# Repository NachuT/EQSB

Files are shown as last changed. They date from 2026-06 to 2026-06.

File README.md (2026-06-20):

# EQSB
As a proud Iphone 7+ owner I don't enjoy many of the new updates that Apple pushes to IOS but a feature I really wish was availible to me is the built in equalizer that is now availible on IOS 27.

Screenshot 2026-06-18 at 9 42 23 PM

This prompted me to think about _physical_ equalizers where you can move physical sliders to create the changes to the music feel which led me to create this USB equalizer.

## How it works
- First, when the USB-C port is conencted to a device a USB Audio IC by TI identifies it as a audio device for us. It also splits the audio from D+ D- into Left and Right.
- Simultaneous to this a charge pump outputs a -5v value from a 5v USB input
- These voltages are used in a series of different buffers, gyrators(a op-amp configuration to simulate a inductor) and summing amplifiers
- The gyrators also have slide potentiometers attached to them allowing for an adujustable frequency to change the amounts of different frequencies of sound
- Then the adjusted left and right audio is fed into a headphone jack for listening 

## Schematic:
Screenshot 2026-06-18 at 9 52 12 PM

## PCB:
Screenshot 2026-06-18 at 9 53 24 PM

## 3d model:
Screenshot 2026-06-18 at 9 55 54 PM

## With Cad:
Screenshot 2026-06-20 at 2 28 49 PM

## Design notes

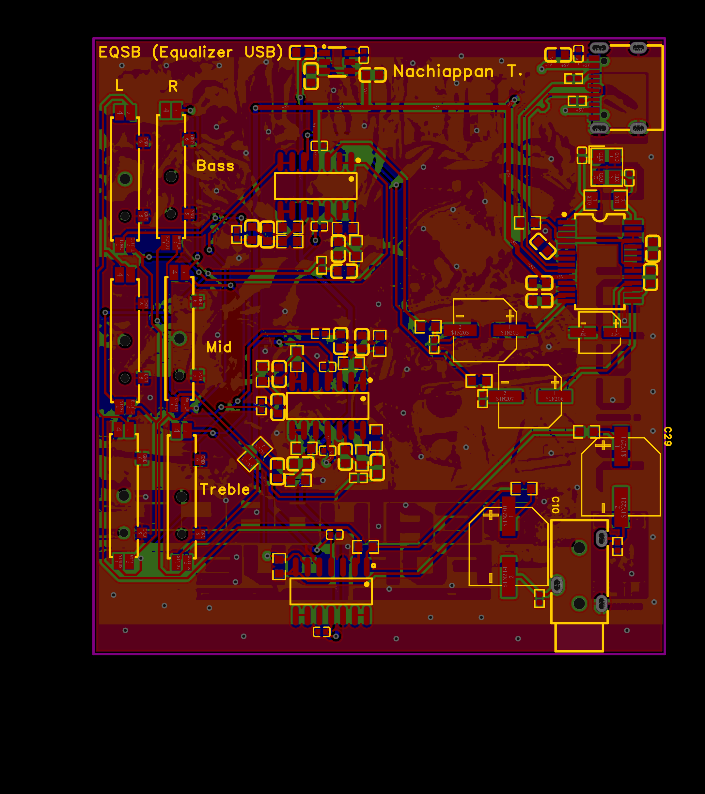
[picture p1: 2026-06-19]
PCB/PCB_PCB1_2026-06-18.png

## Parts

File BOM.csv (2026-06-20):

Name | Price | Shipping+custom+tax | Total | Note
PCB | 95.72 | 77.29 | 173.01 | No idea why shipping is this much it isnt letting me choose global standard direct line

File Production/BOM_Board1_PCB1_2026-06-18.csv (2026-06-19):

Item # | Quantity per board | Comment | Reference designators | Footprint | Value | Manufacturer Part | Manufacturer | Supplier Part | Supplier | Unique ID | Pin Count | Category | LCSC Stock | LCSC Price | JLCPCB Stock | JLCPCB Price | Layer | Mounting Style | Add into BOM | Convert to PCB | 3D Model Title | Device | Name | 3D Model Transform | JLCPCB Part Class | Description | sourceId | spicePre
1 | 7 | 100nF | C1,C30,C31,C32,C33,C34,C35 | C0402 | 100nF | CL05B104KB54PNC | SAMSUNG(三星) | C307331 | LCSC | UNIQUEC1,UNIQUEC1_0,UNIQUEC1_1,UNIQUEC1_2,UNIQUEC1_3,UNIQUEC1_4,UNIQUEC1_5 | 2 | Capacitors:Multilayer Ceramic Capacitors MLCC - SMD/SMT |  |  | 8247341 | 0.0012 | T | SMT | yes |  | C0402_L1.0-W0.5-H0.5 | CL05B104KB54PNC | 100nF | 39.37,19.685,0,0,0,0,0,0,0 | Basic Part | Capacitance:100nF Tolerance:±10% Tolerance:±10% Voltage Rating:50V Temperature Coefficient:X7R
2 | 2 | 10uF | C2,C36 | C0603 | 10uF | CL10A106MA8NRNC | SAMSUNG(三星) | C96446 | LCSC | UNIQUEC2,UNIQUEC2_0 | 2 | Capacitors:Multilayer Ceramic Capacitors MLCC - SMD/SMT |  |  | 2493229 | 0.008 | T | SMT | yes |  | C0603_L1.6-W0.8-H0.8 | CL10A106MA8NRNC | 10uF | 62.992,31.496,0,0,0,0,0,0,0 | Basic Part | Capacitance:10uF Tolerance:±20% Tolerance:±20% Voltage Rating:25V Temperature Coefficient:X5R
3 | 2 | 22pF | C3,C4 | C0402 | 22pF | 0402CG220J500NT | FH(风华) | C1555 | LCSC | UNIQUEC3,UNIQUEC4 | 2 | Capacitors:Multilayer Ceramic Capacitors MLCC - SMD/SMT |  |  | 653991 | 0.0009 | T | SMT | yes |  | C0402_L1.0-W0.5-H0.5 | 0402CG220J500NT | 22pF | 39.37,19.685,0,0,0,0,0,0,0 | Basic Part | Capacitance:22pF Tolerance:±5% Tolerance:±5% Voltage Rating:50V Temperature Coefficient:C0G
4 | 5 | 1uF | C5,C6,C7,C8,C9 | C0603 | 1uF | CL10A105KB8NNNC | SAMSUNG(三星) | C15849 | LCSC | gge4,gge4_0,gge5,gge5_0,gge6 | 2 | Capacitors:Multilayer Ceramic Capacitors MLCC - SMD/SMT |  |  | 5154988 | 0.002 | T | SMT | yes |  | C0603_L1.6-W0.8-H0.8 | CL10A105KB8NNNC | 1uF | 62.992,31.496,0,0,0,0,0,0,0 | Basic Part | Capacitance:1uF Tolerance:±10% Tolerance:±10% Voltage Rating:50V Temperature Coefficient:X5R
5 | 2 | 470uF | C10,C29 | CAP-SMD_BD8.0-L8.3-W8.3-FD | 470uF | RVT1C471M0810 | Chengx(承兴) | C82006 | LCSC | gge17,gge18 | 2 | Capacitors:Aluminum Electrolytic Capacitors - SMD |  |  | 28 | 0.0267 | T | SMT | yes |  | CAP-SMD_BD8.0-L8.3-W8.3-FD | RVT1C471M0810_C82006 | 470uF | 393.7,326.771,0,180,0,0,0,0,0 | Extended Part | Capacitance:470uF Tolerance:±20% Tolerance:±20% Voltage Rating:16V Ripple Current:- Equivalent Series Resistance(ESR):- Diameter:8mm Height - Seated (Max):10.2mm Lifetime:2000hrs@105℃ Operating Temperature:-45℃~+105℃ Operating Temperature:-45℃~+105℃
6 | 2 | 100uF | C11,C12 | CAP-SMD_BD6.3-L6.6-W6.6-FD | 100uF | RVT1V101M0607 | Chengx(承兴) | C82002 | LCSC | UNIQUEC11,UNIQUEC12 | 2 | Capacitors:Aluminum Electrolytic Capacitors - SMD |  |  | 4758 | 0.0139 | T | SMT | yes |  | CAP-SMD_BD6.3-L6.6-W6.6-FD | RVT1V101M0607_C82002 | 100uF | 307.086,259.842,0,180,0,0,0,0,0 | Extended Part | Capacitance:100uF Tolerance:±20% Tolerance:±20% Voltage Rating:35V Ripple Current:- Equivalent Series Resistance(ESR):- Diameter:6.3mm Height - Seated (Max):7.7mm Lifetime:2000hrs@105℃ Operating Temperature:-45℃~+105℃ Operating Temperature:-45℃~+105℃
7 | 2 | 2.2uF | C13,C15 | C0603 | 2.2uF | CL10A225KO8NNNC | SAMSUNG(三星) | C23630 | LCSC | UNIQUEC13,UNIQUEC15 | 2 | Capacitors:Multilayer Ceramic Capacitors MLCC - SMD/SMT |  |  | 1038072 | 0.0014 | T | SMT | yes |  | C0603_L1.6-W0.8-H0.8 | CL10A225KO8NNNC | 2.2uF | 62.992,31.496,0,0,0,0,0,0,0 | Basic Part | Capacitance:2.2uF Tolerance:±10% Tolerance:±10% Voltage Rating:16V Temperature Coefficient:X5R
8 | 1 | 1uF | C14 | C0402 | 1uF | CL05A105KA5NQNC | SAMSUNG(三星) | C52923 | LCSC | UNIQUEC14 | 2 | Capacitors:Multilayer Ceramic Capacitors MLCC - SMD/SMT |  |  | 3337358 | 0.0022 | T | SMT | yes |  | C0402_L1.0-W0.5-H0.5 | CL05A105KA5NQNC | 1uF | 39.37,19.685,0,0,0,0,0,0,0 | Basic Part | Capacitance:1uF Tolerance:±10% Tolerance:±10% Voltage Rating:25V Temperature Coefficient:X5R
9 | 2 | 470nF | C16,C22 | C0603 | 470nF | CL10B474KA8NNNC | SAMSUNG(三星) | C1623 | LCSC | UNIQUEC16,UNIQUEC22 | 2 | Capacitors:Multilayer Ceramic Capacitors MLCC - SMD/SMT |  |  | 324484 | 0.0014 | T | SMT | yes |  | C0603_L1.6-W0.8-H0.8 | CL10B474KA8NNNC | 470nF | 62.992,31.496,0,0,0,0,0,0,0 | Basic Part | Capacitance:470nF Tolerance:±10% Tolerance:±10% Voltage Rating:25V Temperature Coefficient:X7R
10 | 2 | 47nF | C17,C23 | C0603 | 47nF | CL10B473KB8NNNC | SAMSUNG(三星) | C1622 | LCSC | UNIQUEC17,UNIQUEC23 | 2 | Capacitors:Multilayer Ceramic Capacitors MLCC - SMD/SMT |  |  | 332403 | 0.0013 | T | SMT | yes |  | C0603_L1.6-W0.8-H0.8 | CL10B473KB8NNNC | 47nF | 62.992,31.496,0,0,0,0,0,0,0 | Basic Part | Capacitance:47nF Tolerance:±10% Tolerance:±10% Voltage Rating:50V Temperature Coefficient:X7R
11 | 2 | 22nF | C18,C24 | C0603 | 22nF | CL10B223KB8NNNC | SAMSUNG(三星) | C21122 | LCSC | UNIQUEC18,UNIQUEC24 | 2 | Capacitors:Multilayer Ceramic Capacitors MLCC - SMD/SMT |  |  | 350252 | 0.0012 | T | SMT | yes |  | C0603_L1.6-W0.8-H0.8 | CL10B223KB8NNNC | 22nF | 62.992,31.496,0,0,0,0,0,0,0 | Basic Part | Capacitance:22nF Tolerance:±10% Tolerance:±10% Voltage Rating:50V Temperature Coefficient:X7R
12 | 4 | 2.2nF | C19,C21,C25,C27 | C0603 | 2.2nF | 0603B222K500NT | FH(风华) | C1604 | LCSC | UNIQUEC19,UNIQUEC21,UNIQUEC25,UNIQUEC27 | 2 | Capacitors:Multilayer Ceramic Capacitors MLCC - SMD/SMT |  |  | 325168 | 0.0008 | T | SMT | yes |  | C0603_L1.6-W0.8-H0.8 | 0603B222K500NT | 2.2nF | 62.992,31.496,0,0,0,0,0,0,0 | Basic Part | Capacitance:2.2nF Tolerance:±10% Tolerance:±10% Voltage Rating:50V Temperature Coefficient:X7R
13 | 2 | 220pF | C20,C26 | C0603 | 220pF | GCM1885C2A221JA16D | muRata(村田) | C388907 | LCSC | UNIQUEC20,UNIQUEC26 | 2 | Capacitors:Multilayer Ceramic Capacitors MLCC - SMD/SMT |  |  | 1587716 | 0.0036 | T | SMT | yes |  | C0603_L1.6-W0.8-H0.8 | GCM1885C2A221JA16D | 220pF | 62.992,31.496,0,0,0,0,0,0,0 | Extended Part | Capacitance:220pF Tolerance:±5% Tolerance:±5% Voltage Rating:100V Temperature Coefficient:C0G
14 | 1 | 10uF | C28 | CAP-SMD_BD4.0-L4.3-W4.3-FD-LS5.1 | 10uF | RVT1E100M0405 | ACMECON(鼎容) | C22383790 | LCSC | gge3 | 2 | Capacitors:Aluminum Electrolytic Capacitors - SMD |  |  | 35990 | 0.0025 | T | SMT | yes |  | CAP-SMD_BD4.0-L4.3-W4.3-FD-LS5.1 | RVT1E100M0405_C22383790 | 10uF | 200.787,169.291,0,180,0,0,0,0,0 | Extended Part | Capacitance:10uF Tolerance:±20% Tolerance:±20% Voltage Rating:25V Diameter:4mm Height - Seated (Max):5.4mm Operating Temperature:-55℃~+105℃ Operating Temperature:-55℃~+105℃
15 | 1 | PJ-3200 | CN1 | AUDIO-TH_PJ-3200 |  | PJ-3200 | XKB Connection(中国星坤) | C2689690 | LCSC | UNIQUECN1 | 3 | Connectors:Audio Connectors |  |  | 11318 | 0.016 | T | DIP | yes |  | AUDIO-TH_PJ-3200 | PJ-3200 | PJ-3200 | 551.18,236.22,0,0,0,0,-63.07,-0.354,-110.236 | Extended Part | Connector Type:3.5mm Headphone Jack Current Rating:500mA Voltage Rating (Max):30V Operating Temperature:-20℃~+70℃ Operating Temperature:-20℃~+70℃
16 | 2 | 5.1kΩ | R1,R2 | R0402 | 5.1kΩ | 0402WGF5101TCE | UNI-ROYAL(厚声) | C25905 | LCSC | gge9,gge10 | 2 | Resistors:Chip Resistor - Surface Mount |  |  | 2398402 | 0.0002 | T | SMT | yes |  | R0402_L1.0-W0.5-H0.4 | 0402WGF5101TCE | 5.1kΩ | 39.37,19.685,0,0,0,0,0,0,0 | Basic Part | Type:Thick Film Resistor Resistance:5.1kΩ Tolerance:±1% Tolerance:±1% Power(Watts):62.5mW Voltage-Supply(Max):50V Temperature Coefficient:±100ppm/℃ Temperature Coefficient:±100ppm/℃ Operating Temperature:-55℃~+155℃ Operating Temperature:-55℃~+155℃
17 | 2 | 100Ω | R3,R4 | R0603 | 100Ω | 0603WAF1000T5E | UNI-ROYAL(厚声) | C22775 | LCSC | UNIQUER3,UNIQUER4 | 2 | Resistors:Chip Resistor - Surface Mount |  |  | 7821642 | 0.0004 | T | SMT | yes |  | R0603 | 0603WAF1000T5E | 100Ω | 31.8897,63.7794,0,90,0,0,0,0,0 | Basic Part | Type:Thick Film Resistors Resistance: Tolerance:±1% Tolerance:±1% Power(Watts): Overload Voltage (Max): Temperature Coefficient:±200ppm/℃ Temperature Coefficient:±200ppm/℃ Operating Temperature Range:-55℃~+155℃ Operating Temperature Range:-55℃~+155℃
18 | 1 | 1.5kΩ | R5 | R0603 | 1.5kΩ | 0603WAF1501T5E | UNI-ROYAL(厚声) | C22843 | LCSC | UNIQUER5 | 2 | Resistors:Chip Resistor - Surface Mount |  |  | 1286654 | 0.0002 | T | SMT | yes |  | R0603 | 0603WAF1501T5E | 1.5kΩ | 31.8897,63.7794,0,90,0,0,0,0,0 | Basic Part | Type:Thick Film Resistor Resistance:1.5kΩ Tolerance:±1% Tolerance:±1% Power(Watts):100mW Voltage-Supply(Max):75V Temperature Coefficient:±100ppm/℃ Temperature Coefficient:±100ppm/℃ Operating Temperature:-55℃~+155℃ Operating Temperature:-55℃~+155℃
19 | 1 | 1MΩ | R6 | R1206 | 1MΩ | 1206W4F1004T5E | UNI-ROYAL(厚声) | C17927 | LCSC | UNIQUER6 | 2 | Resistors:Chip Resistor - Surface Mount |  |  | 1028869 | 0.0007 | T | SMT | yes |  | R1206_L3.2-W1.6-H0.6 | 1206W4F1004T5E | 1MΩ | 125.984,62.992,0,0,0,0,0,0,0 | Basic Part | Type:Thick Film Resistor Resistance:1MΩ Tolerance:±1% Tolerance:±1% Power(Watts):250mW Voltage-Supply(Max):200V Temperature Coefficient:±100ppm/℃ Temperature Coefficient:±100ppm/℃ Operating Temperature:-55℃~+155℃ Operating Temperature:-55℃~+155℃
20 | 6 | 10kΩ | R7,R11,R15,R19,R23,R27 | RES-ADJ-SMD_L13.2-W3.0_RS08U111Z001 | 10kΩ | RS08U111Z001 | ALPSALPINE(阿尔卑斯阿尔派) | C202411 | LCSC | UNIQUER7,UNIQUER11,UNIQUER15,UNIQUER19,UNIQUER23,UNIQUER27 | 6 | Resistors:Potentiometers, Variable Resistors |  |  | 1383 | 0.1452 | T | SMT | yes |  |  | RS08U111Z001 | 10kΩ |  | Extended Part | Resistance: Tolerance:±30% Tolerance:±30%
21 | 5 | 1kΩ | R8,R12,R16,R20,R24 | R0402 | 1kΩ | 0402WGF1001TCE | UNI-ROYAL(厚声) | C11702 | LCSC | UNIQUER8,UNIQUER12,UNIQUER16,UNIQUER20,UNIQUER24 | 2 | Resistors:Chip Resistor - Surface Mount |  |  | 3123168 | 0.0002 | T | SMT | yes |  | R0402_L1.0-W0.5-H0.4 | 0402WGF1001TCE | 1kΩ | 39.37,19.685,0,0,0,0,0,0,0 | Basic Part | Type:Thick Film Resistor Resistance:1kΩ Tolerance:±1% Tolerance:±1% Power(Watts):62.5mW Voltage-Supply(Max):50V Temperature Coefficient:±100ppm/℃ Temperature Coefficient:±100ppm/℃ Operating Temperature:-55℃~+155℃ Operating Temperature:-55℃~+155℃
22 | 6 | 680Ω | R9,R14,R18,R21,R26,R30 | R0603 | 680Ω | 0603WAF6800T5E | UNI-ROYAL(厚声) | C23228 | LCSC | UNIQUER9,UNIQUER14,UNIQUER18,UNIQUER21,UNIQUER26,UNIQUER30 | 2 | Resistors:Chip Resistor - Surface Mount |  |  | 931729 | 0.0002 | T | SMT | yes |  | R0603 | 0603WAF6800T5E | 680Ω | 31.8897,63.7794,0,90,0,0,0,0,0 | Basic Part | Type:Thick Film Resistors Resistance: Tolerance:±1% Tolerance:±1% Power(Watts): Overload Voltage (Max): Temperature Coefficient:±100ppm/℃ Temperature Coefficient:±100ppm/℃ Operating Temperature Range:-55℃~+155℃ Operating Temperature Range:-55℃~+155℃
23 | 6 | 47kΩ | R10,R13,R17,R22,R25,R29 | R0603 | 47kΩ | 0603WAF4702T5E | UNI-ROYAL(厚声) | C25819 | LCSC | UNIQUER10,UNIQUER13,UNIQUER17,UNIQUER22,UNIQUER25,UNIQUER29 | 2 | Resistors:Chip Resistor - Surface Mount |  |  | 1932185 | 0.0003 | T | SMT | yes |  | R0603 | 0603WAF4702T5E | 47kΩ | 31.8897,63.7794,0,90,0,0,0,0,0 | Basic Part | Type:Thick Film Resistor Resistance:47kΩ Tolerance:±1% Tolerance:±1% Power(Watts):100mW Voltage-Supply(Max):75V Temperature Coefficient:±100ppm/℃ Temperature Coefficient:±100ppm/℃ Operating Temperature:-55℃~+155℃ Operating Temperature:-55℃~+155℃
24 | 1 | 1kΩ | R28 | R0805 | 1kΩ | 0805W8F1001T5E | UNI-ROYAL(厚声) | C17513 | LCSC | gge11 | 2 | Resistors:Chip Resistor - Surface Mount |  |  | 6152575 | 0.0005 | T | SMT | yes |  | R0805_L2.0-W1.3-H0.6 | 0805W8F1001T5E | 1kΩ | 78.74,51.181,0,0,0,0,0,-0.0005,0 | Basic Part | Type:Thick Film Resistors Resistance:1kΩ Tolerance:±1% Tolerance:±1% Power(Watts): Overload Voltage (Max): Temperature Coefficient:±100ppm/℃ Temperature Coefficient:±100ppm/℃ Operating Temperature Range:-55℃~+155℃ Operating Temperature Range:-55℃~+155℃
25 | 2 | 10kΩ | R31,R32 | R0603 | 10kΩ | 0603WAF1002T5E | UNI-ROYAL(厚声) | C25804 | LCSC | UNIQUER31,UNIQUER32 | 2 | Resistors:Chip Resistor - Surface Mount |  |  | 0 | 0.0002 | T | SMT | yes |  | R0603 | 0603WAF1002T5E | 10kΩ | 31.8897,63.7794,0,90,0,0,0,0,0 | Basic Part | Type:Thick Film Resistor Resistance:10kΩ Tolerance:±1% Tolerance:±1% Power(Watts):100mW Voltage-Supply(Max):75V Temperature Coefficient:±100ppm/℃ Temperature Coefficient:±100ppm/℃ Operating Temperature:-55℃~+155℃ Operating Temperature:-55℃~+155℃
26 | 2 | 10kΩ | R33,R34 | R0402 | 10kΩ | 0402WGF1002TCE | UNI-ROYAL(厚声) | C25744 | LCSC | gge1,gge2 | 2 | Resistors:Chip Resistor - Surface Mount |  |  | 1867128 | 0.0002 | T | SMT | yes |  | R0402_L1.0-W0.5-H0.4 | 0402WGF1002TCE | 10kΩ | 39.37,19.685,0,0,0,0,0,0,0 | Basic Part | Type:Thick Film Resistor Resistance:10kΩ Tolerance:±1% Tolerance:±1% Power(Watts):62.5mW Voltage-Supply(Max):50V Temperature Coefficient:±100ppm/℃ Temperature Coefficient:±100ppm/℃ Operating Temperature:-55℃~+155℃ Operating Temperature:-55℃~+155℃
27 | 2 | 4.7Ω | R35,R37 | R0603 | 4.7Ω | 0603WAF470KT5E | UNI-ROYAL(厚声) | C23164 | LCSC | gge15,gge16 | 2 | Resistors:Chip Resistor - Surface Mount |  |  | 337372 | 0.0004 | T | SMT | yes |  | R0603 | 0603WAF470KT5E | 4.7Ω | 31.8897,63.7794,0,90,0,0,0,0,0 | Basic Part | Type:Thick Film Resistor Resistance:4.7Ω Tolerance:±1% Tolerance:±1% Power(Watts):100mW Voltage-Supply(Max):75V Temperature Coefficient:±400ppm/℃ Temperature Coefficient:±400ppm/℃ Operating Temperature:-55℃~+155℃ Operating Temperature:-55℃~+155℃
28 | 2 | 51kΩ | R36,R38 | R0402 | 51kΩ | 0402WGF5102TCE | UNI-ROYAL(厚声) | C25794 | LCSC | gge7,gge8 | 2 | Resistors:Chip Resistor - Surface Mount |  |  | 380853 | 0.0002 | T | SMT | yes |  | R0402_L1.0-W0.5-H0.4 | 0402WGF5102TCE | 51kΩ | 39.37,19.685,0,0,0,0,0,0,0 | Basic Part | Type:Thick Film Resistors Resistance:51kΩ Tolerance:±1% Tolerance:±1% Power(Watts): Overload Voltage (Max): Temperature Coefficient:±100ppm/℃ Temperature Coefficient:±100ppm/℃ Operating Temperature Range:-55℃~+155℃ Operating Temperature Range:-55℃~+155℃
29 | 1 | PCM2704DB | U1 | SSOP-28_L10.2-W5.3-P0.65-LS7.8-TL |  | PCM2704DB | TI(德州仪器) | C2877458 | LCSC | UNIQUEU1 | 28 | Data Acquisition:ADCs/DACs - Special Purpose |  |  | 50 | 1.117 | T | SMT | yes |  | SSOP-28_L10.2-W5.3-H2.0-LS7.8-P0.65 | PCM2704DB | PCM2704DB | 401.574,307.086,0,270,0,0,0,0,0 | Extended Part | Resolution:16 Number of Channels:2 Voltage - Supply:3V~5.25V Voltage - Supply:3V~5.25V Interface Type:I2S Operating Temperature:-25℃~+85℃ Operating Temperature:-25℃~+85℃
30 | 1 | LM2776DBVR | U2 | SOT-23-6_L2.9-W1.6-P0.95-LS2.8-BR |  | LM2776DBVR | TI(德州仪器) | C69527 | LCSC | UNIQUEU2 | 6 | Power Management (PMIC):Charge Pumps |  |  | 10555 | 0.107 | T | SMT | yes |  | SOT-23-6_L2.9-W1.6-H1.5-LS2.8-P0.95 | LM2776DBVR | LM2776DBVR | 110.73671,114.173,0,180,0,0,0.001,-0.003,0 | Extended Part | Operating Voltage:2.7V~5.5V Operating Voltage:2.7V~5.5V Quiescent Current:200uA Output Resistance:2.5Ω Energy Efficiency:90% Switching Frequency:2MHz Operating Temperature:-40℃~+85℃ Operating Temperature:-40℃~+85℃ Function:Inverted PFM Mode:Support Output
31 | 3 | OPA1654AIDR | U6,U7,U8 | SOIC-14_L8.7-W3.9-P1.27-LS6.0-BL |  | OPA1654AIDR | TI(德州仪器) | C30026 | LCSC | gge12,gge13,gge14 | 14 | Amplifiers/Comparators:Audio Amplifiers |  |  | 2264 | 0.4587 | T | SMT | yes |  | SOIC-14_L8.6-W3.9-H1.8-LS6.0-P1.27 | OPA1654AIDR | OPA1654AIDR | 338.583,236.22,0,0,0,0,0,0.001,0 | Extended Part | Class:- Speaker Channels:4-Channel Output Power:- Total Harmonic Distortion + Noise (THD+N):0.00005% Quiescent Current:2mA Signal-to-Noise Ratio:- Power Supply Rejection Ratio (PSRR):110dB Efficiency:- Number of Inputs:- Features:- Voltage - Supply:2.25V~
32 | 1 | TYPE-C 16PIN 2MD(073) | USB1 | USB-C-SMD_TYPE-C-16PIN-2MD-073 |  | TYPE-C 16PIN 2MD(073) | SHOU HAN(首韩) | C2765186 | LCSC | UNIQUEUSB1 | 16 | Connectors:USB Connectors |  |  | 1377026 | 0.011 | T | DIP | yes |  | USB-C-SMD_TYPE-C-6PIN-2MD-073 | TYPE-C 16PIN 2MD(073) | TYPE-C 16PIN 2MD(073) | 351.9678,298.4246,0,0,0,0,0,-47.244,-35.433 | Extended Part | Connector Type:Type-C Protocol Standard:- Gender:Female Mounting Type:Surface Mount, Right Angle Number of Contacts:16P Number of Ports:1 Current Rating-Power:3A Voltage Rating:5V Connect-Disconnect Life:10,000 Cycles Supplementary Features:- Center Heigh
33 | 1 | 12MHz | X1 | CRYSTAL-SMD_4P-L3.2-W2.5-BL | 12MHz | X322512MSB4SI | YXC(扬兴晶振) | C9002 | LCSC | UNIQUEX1 | 4 | Crystals, Oscillators, Resonators:Crystals |  |  | 225763 | 0.015 | T | SMT | yes |  | CRYSTAL-SMD_4P-L3.2-W2.5-BL | X322512MSB4SI | 12MHz | 125.984,98.425,0,0,0,0,0,0,0 | Basic Part | Type:Crystal Oscillator Frequency:12MHz Normal temperature Frequency Tolerance:±10ppm Normal temperature Frequency Tolerance:±10ppm Load Capacitance:20pF Frequency Stability:±20ppm Frequency Stability:±20ppm Operating Temperature:-40℃~+85℃ Operating Tempe

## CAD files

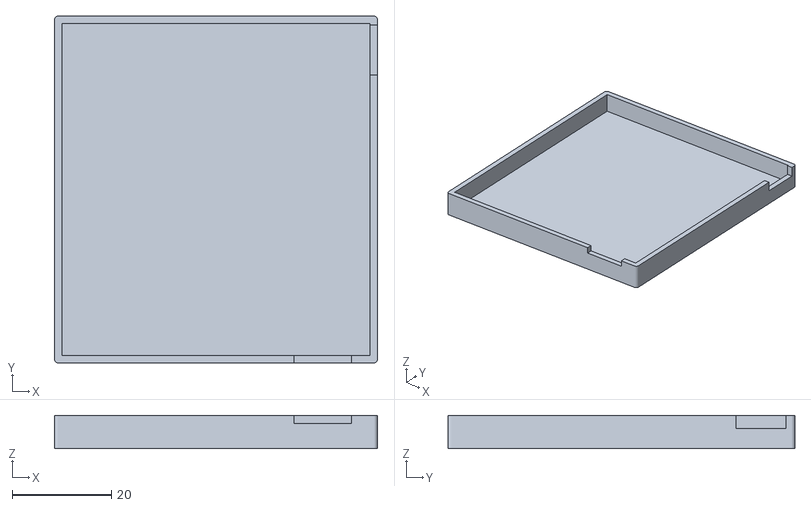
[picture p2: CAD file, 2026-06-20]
CAD/Bottom.stl
65.0 x 69.9 x 6.67

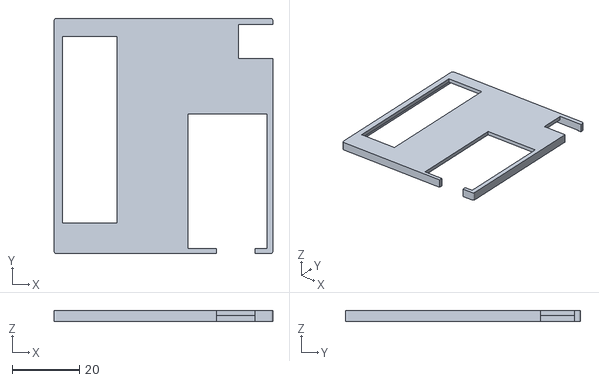
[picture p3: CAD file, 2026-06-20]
CAD/Top.stl
65.0 x 69.9 x 3.33

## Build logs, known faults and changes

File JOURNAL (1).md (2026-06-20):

<!--
  This journal is auto generated by Stasis.
-->
# CAD

_Time spent: 5h_

I genuinely hate doing CAD I am only used to autodesk software but fusion wasnt downloading properly for like a good hour so then I switched to Onshape which was completely useless and I could barely even make the cad load so at that point I just chose to make the case in the easyeda case CAD designer which took me a while to learn but I still got the end result I wanted.

Screenshot 2026-06-20 at 2 42 49 PM

# Used wrong IC

_Time spent: 0.5h_

It turns out the Op amp that I was using before is not actually meant for audio and it has high auidible dropoff in the audio and it would sound bad. For this reason I switched to the TI OPA1654AIDR cus it is actually meant for audio and it was pretty much a drop in replacement in terms of routing. Also because of this I changed a resistor value from 100 to 4.7 ohms as I do not need that much protection anymore.

Screenshot 2026-06-18 at 7.36.44 PM

# PCB building

_Time spent: 3.5h_

Honestly the routing was much easier than last project because of my layout 90% of the passives were all super short direct traces and i was able to have 5V rails throughout the board for power. To get some of the pots to work I had to add and work around vias but that also required slight adjustment to some small components as well. After that I created a top and bottom ground plane which missed quite a few grounds so I had to reroute some areas to open them up to more plane space which after via stitching got everything connected. After this I also added some cool front and back silkscreen as well to the board.
Screenshot 2026-06-18 at 9.25.49 AM

# Did Layout

_Time spent: 2h_

If you saw my last project you know my layout was super trash and that wasted a lot of time so this time i wanted to focus more on how the routing will look rather than purely placing components where it "looks" neat.
I am still definitely a litle scared of those slide pots esp since I made how they go to each opamp super weird so hopefully I will be able to get everything done.



# Finished Schematic

_Time spent: 4.5h_

I then did the rest of the pcb layout which included 6 Op-amps which were TI LM series becuase I have used those quad op-amps before. For these op-amps I used a calcutator for gyrators to find the different bands at which I could adjust for treble, mid, and bass. The other opamps were used for breating the input through a buffer and summing opamp for output. For the extra to op amps unused I just made those unity gain amplifiers. I also included a charge pump as well for the -5v creation and lastly watched this video to read headphone jack schematics to make them [video](https://www.youtube.com/watch?v=GypQx7ZjBp4).



# Schematic for the USB AUdio

_Time spent: 4h_

I first made the USB-C stuff with the crystal which was pretty fast and easy since I already did something like this for another project. What was much more difficult was learning how to use the PCM2704DB cus a bunch of the datasheets and sample schematics online had different implementations of this IC. For example some sources were saying the 1M ohm resistor was internal to the actual IC but then I actually checked the block diagram which I still barely understand and found that it was not internal and I needed to add it.
Screenshot 2026-06-18 at 8.07.55 AM



# Research

_Time spent: 3h_

I just finished the research required for this project and honestly I don't think it will be as hard as initially anticipated but I may regret that staatement. Essentially what I need to do is use 5 potentiometers, specifically dual gang pots as in stereo audio you want both ears to be in sync. From there there will be a gyrator circuit which essentially just emulates a inductor allowing specific frequencies to be controlled like the 5 band eqs that headphones have. This will all work by using a USB Audio accessory IC as well as a headphone jack plug so you can hear it after equalization.

Credit: wikipedia



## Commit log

2026-06-19 Update and rename tableConvert.com_1udar2.csv to BOM.csv
    [BOM.csv, tableConvert.com_1udar2.csv]
2026-06-19 Fix BOM.csv formatting issue
    [BOM.csv]
2026-06-20 CAD added
2026-06-20 Update PCB price and total in BOM.csv
    [BOM.csv]
